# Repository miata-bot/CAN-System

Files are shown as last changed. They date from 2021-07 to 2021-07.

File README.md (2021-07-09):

# Miata CAN System

## Useful Links

* [Gerber Generation for PCBWay](https://www.pcbway.com/blog/help_center/Generate_Gerber_file_from_Kicad.html)
* [Position Generation for PCBWay](https://www.pcbway.com/blog/help_center/Generate_Position_File_in_Kicad.html)

## Underglow Controller

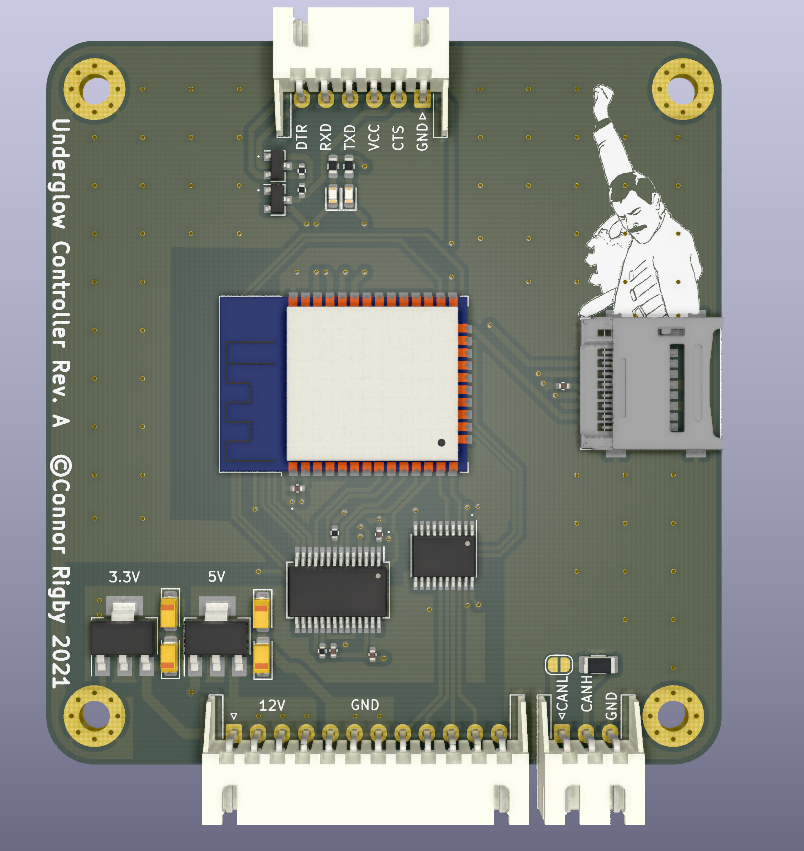
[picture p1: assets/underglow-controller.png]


## Headlight Controller

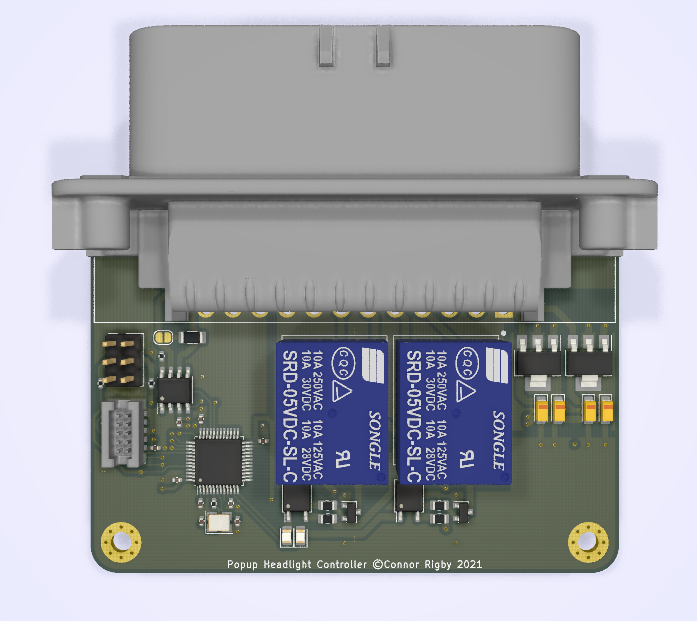
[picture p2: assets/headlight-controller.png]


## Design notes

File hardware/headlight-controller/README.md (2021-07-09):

# LED Controller Hardware design



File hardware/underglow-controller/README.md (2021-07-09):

# LED Controller Hardware design



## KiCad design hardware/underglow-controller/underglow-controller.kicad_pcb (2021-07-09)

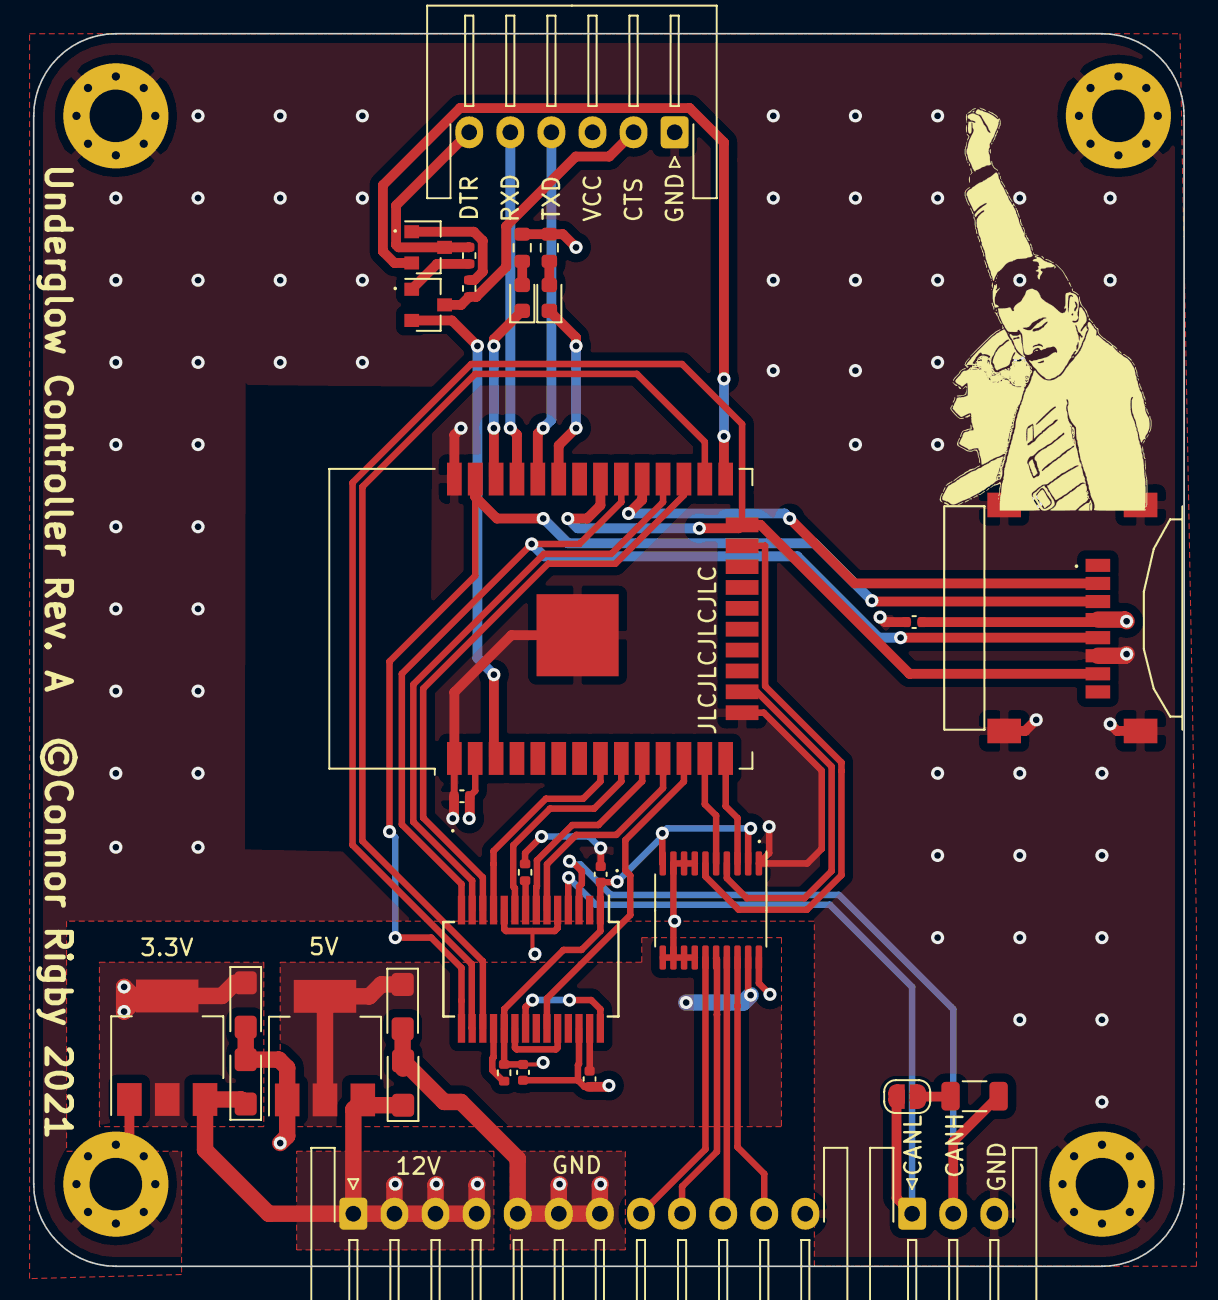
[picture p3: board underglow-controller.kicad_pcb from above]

Board: 4 copper layers, 70.0 x 75.0 mm, 34 parts (0 on the bottom side), 43 nets.

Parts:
C1, C2, C3, C4: 10u; CP_EIA-3216-18_Kemet-A
C5, C6, C7, C8, C9: 100n; C_0402_1005Metric
D1, D2: LED_Small; LED_0603_1608Metric
H1, H2, H3, H4: MountingHole_Pad; MountingHole_3.2mm_M3_Pad_Via
J1: Micro_SD_Card; MOLEX_47219-2001
J2: FTDI; JST_XH_S6B-XH-A-1_1x06_P2.50mm_Horizontal
J3: LEDS; JST_XH_S12B-XH-A-1_1x12_P2.50mm_Horizontal
J4: CAN; JST_XH_S3B-XH-A-1_1x03_P2.50mm_Horizontal
JP1: Jumper_NO_Small; SolderJumper-2_P1.3mm_Open_RoundedPad1.0x1.5mm
Q1, Q2: SS8050; SOT-23
R1, R2, R5, R6: 10k; R_0402_1005Metric
R3, R4: R_Small; R_0603_1608Metric
R7: 120; R_1206_3216Metric
U1: AMS1117-3.3; SOT-223-3_TabPin2
U2: TXS0108EPW; TSSOP-20_4.4x6.5mm_P0.65mm
U3: AMS1117-5.0; SOT-223-3_TabPin2
U4: ESP32-WROOM-32D; ESP32-WROOM-32
U5: MCP25625-x-SS; SSOP-28_5.3x10.2mm_P0.65mm

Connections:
+3V3: C2.1, C5.2, C6.2, C7.2, C8.2, J1.4, R3.1, R4.1, R5.2, U1.2, U2.2, U2.10, U4.2, U5.1, U5.19
+5V: C4.1, C9.2, U2.19, U3.2, U5.27
+12V: C1.1, C3.1, J3.1, J3.2, J3.3, J3.4, U1.3, U3.3
/CANH: J4.1, JP1.1, U5.4
/CANL: J4.2, R7.2, U5.3
/CAN_INT: U4.28, U5.13
/CAN_RX0_BF: U4.27, U5.12
/CAN_RX1_BF: U4.8, U5.11
/CAN_TX0_RTS: U4.12, U5.23
/CAN_TX1_RTS: U4.11, U5.6
/CAN_TX2_RTS: U4.10, U5.7
/FTDI_CTS: J2.2, Q1.3, R2.2
/FTDI_DTR: J2.6, Q2.3, R1.2
/FTDI_RX: J2.5, U4.35
/FTDI_TX: J2.4, U4.34
/GPIO0: Q2.2, U4.25
/LED0: U2.4, U4.16
/LED0_OUT: J3.10, U2.17
/LED1: U2.3, U4.14
/LED1_OUT: J3.11, U2.18
/LED2: U2.5, U4.13
/LED2_OUT: J3.9, U2.16
/LED3: U2.6, U4.23
/LED3_OUT: J3.8, U2.15
/RESET: Q1.2, U4.3
/SD_CLK: J1.5, U4.30, U5.14
/SD_CMD: J1.3, U4.37, U5.15
/SD_D0: J1.7, U4.24, U4.31, U5.16
/SD_D3: J1.2, U4.29
/SPI_CS: U4.26, U5.17
/STATUS0: D1.1, U4.33
/STATUS1: D2.1, U4.36
/XTAL_OUT: U4.9, U5.9
GND: C1.2, C2.2, C3.2, C4.2, C5.1, C6.1, C7.1, C8.1, C9.1, H1.1, H2.1, H3.1, H4.1, J1.6, J1.G1, J1.G2, J1.G3, J1.G4, J2.1, J3.5, J3.6, J3.7, J3.12, J4.3, R6.2, U1.1, U2.1, U2.7, U2.8, U2.9, U2.11, U2.12, U2.13, U2.14, U2.20, U3.1, U4.1, U4.15, U4.38, U4.39, U5.5, U5.10, U5.26
unnamed: D1.2, R3.2
unnamed: D2.2, R4.2
unnamed: JP1.2, R7.1
unnamed: Q1.1, R1.1
unnamed: Q2.1, R2.1
unnamed: R5.1, U5.18
unnamed: R6.1, U5.8
unnamed: U5.20, U5.24
unnamed: U5.21, U5.28

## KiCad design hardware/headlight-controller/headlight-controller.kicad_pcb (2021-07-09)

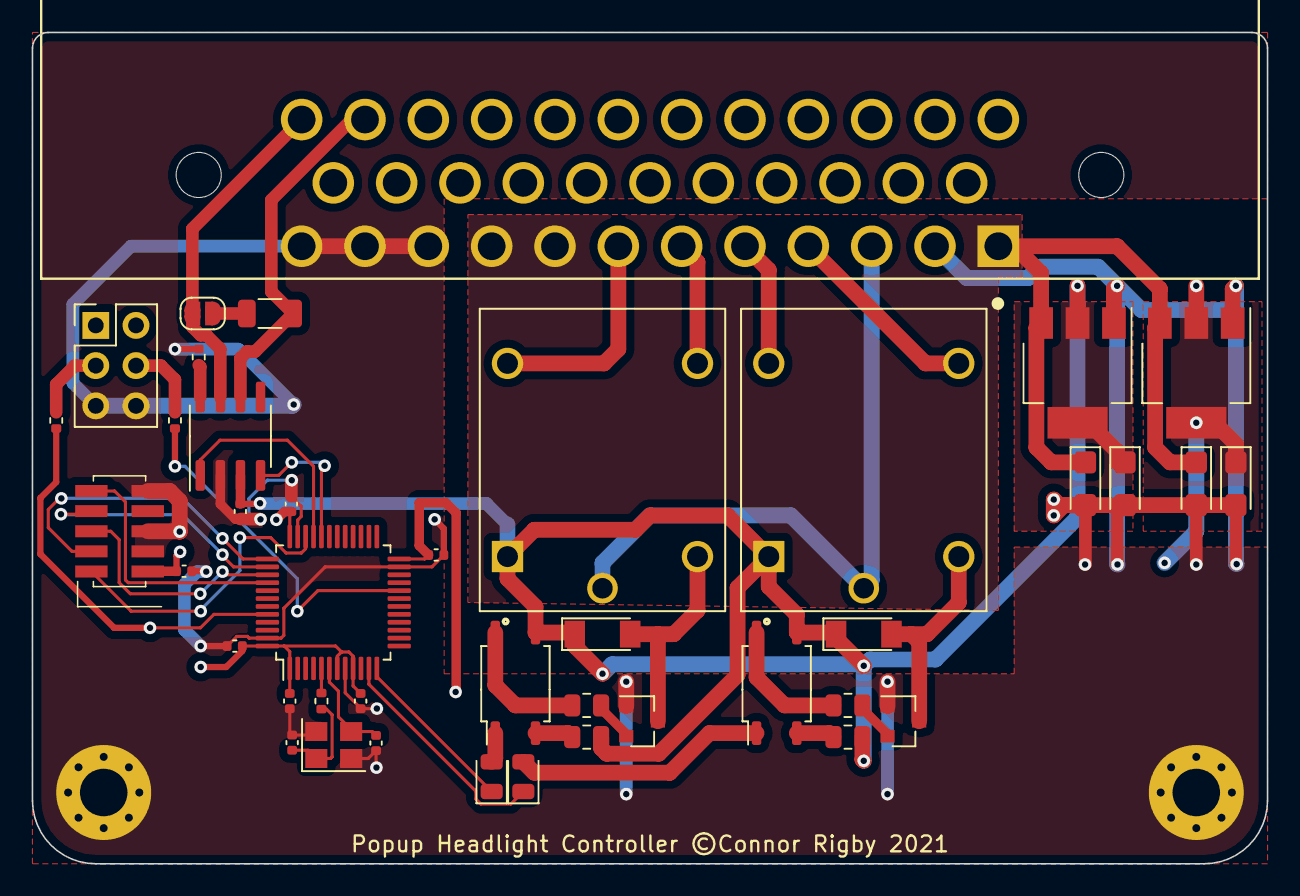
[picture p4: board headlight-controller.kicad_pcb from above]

Board: 2 copper layers, 78.0 x 52.5 mm, 43 parts (0 on the bottom side), 39 nets.

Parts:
C1, C2, C3, C7: 10u; CP_EIA-3216-18_Kemet-A
C4, C6: 12p; C_0402_1005Metric
C5, C8, C9, C10, C11, C12, C13: 100n; C_0402_1005Metric
D1, D2: RED; LED_0805_2012Metric
D3, D4: ZMM5V6; D_MiniMELF
H1, H2: MountingHole_Pad; MountingHole_3mm_Pad_Via
J1: Conn_ARM_JTAG_SWD_10; 20021221-00010C4LF
J2: 776180-1; TE_776180-1
J3: BOOT; PinHeader_2x03_P2.54mm_Vertical
JP1: Jumper_NO_Small; SolderJumper-2_P1.3mm_Open_RoundedPad1.0x1.5mm
K1, K2: SRD-05VDC-SL-C; RELAY_SRD-05VDC-SL-C
Q1, Q2: S8050; SOT-23
R1, R2: 1k; R_0805_2012Metric
R3, R4: 510; R_0805_2012Metric
R5: 120; R_1206_3216Metric
R6, R8: 100K; R_0402_1005Metric
R7: 1M; R_0402_1005Metric
R9: 4.7k; R_0402_1005Metric
U1: AMS1117-3.3; SOT-223-3_TabPin2
U2: AMS1117-5.0; SOT-223-3_TabPin2
U3: STM32F103C8Tx; LQFP-48_7x7mm_P0.5mm
U4: MCP2551-I-SN; SOIC-8_3.9x4.9mm_P1.27mm
U5, U6: EL357N(B)(TA)-G; SOP-4_4.1x4.4mm_P2.54mm
Y1: Crystal_GND24_Small; Crystal_SMD_3225-4Pin_3.2x2.5mm

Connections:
+3V3: C2.1, C5.1, C8.1, C9.1, C10.1, C11.1, C12.1, J1.1, J3.1, J3.2, U1.2, U3.1, U3.7, U3.9, U3.24, U3.36, U3.48
+5V: C7.1, C13.1, D3.1, D4.1, K1.A1, K2.A1, R1.2, R2.2, U2.2, U4.3, U5.3, U6.3
+12V: C1.1, C3.1, J2.1, J2.8, J2.9, U1.3, U2.3
/BOOT0: R6.2, U3.44
/BOOT1: R8.1, U3.20
/CANH: J2.35, JP1.1, U4.7
/CANL: J2.34, R5.1, U4.6
/CAN_RX: U3.32, U4.4
/CAN_TX: U3.33, U4.1
/HL1_DN: J2.7, K1.NC
/HL1_IN: D1.1, U3.12
/HL1_UP: J2.6, K1.NO
/HL2_DN: J2.5, K2.NC
/HL2_IN: D2.1, U3.11
/HL2_UP: J2.4, K2.NO
/HL_COM: J2.3, K1.COM, K2.COM
/HSE_IN: R7.1, U3.5
/HSE_OUT: C6.1, U3.6, Y1.3
/JNTRST: J1.10, U3.40
/SWDCLK: J1.4, U3.37
/SWDIO: J1.2, U3.34
/SWO: J1.6, U3.39
/TDI: J1.8, U3.38
GND: C1.2, C2.2, C3.2, C4.2, C5.2, C6.2, C7.2, C8.2, C9.2, C10.2, C11.2, C12.2, C13.2, H1.1, H2.1, J1.3, J1.5, J1.9, J2.2, J2.10, J2.11, J2.12, J3.5, J3.6, Q1.1, Q2.1, R9.1, U1.1, U2.1, U3.8, U3.23, U3.35, U3.47, U4.2, Y1.2, Y1.4
unnamed: C4.1, R7.2, Y1.1
unnamed: D1.2, U5.1
unnamed: D2.2, U6.1
unnamed: D3.2, K1.A2, Q1.3
unnamed: D4.2, K2.A2, Q2.3
unnamed: J3.3, R6.1
unnamed: J3.4, R8.2
unnamed: JP1.2, R5.2
unnamed: Q1.2, R3.1
unnamed: Q2.2, R4.1
unnamed: R1.1, U5.2
unnamed: R2.1, U6.2
unnamed: R3.2, U5.4
unnamed: R4.2, U6.4
unnamed: R9.2, U4.8

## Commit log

2021-07-07 Progress on routing
    [miata-underglow.kicad_pcb, miata-underglow.sch]
2021-07-08 More routing progress
    [miata-underglow.kicad_pcb, miata-underglow.sch]
2021-07-08 p much complete i think
    [miata-underglow.kicad_pcb]
2021-07-08 Hardware Rev A
    [miata-underglow-B_Cu.gbl, miata-underglow-B_Mask.gbs, miata-underglow-B_Paste.gbp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]
2021-07-08 Add Second controller for Headlights
    [miata-headlight-controller.kicad_pcb, miata-headlight-controller.sch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]
2021-07-09 Restructure project
    [headlight-controller.kicad_pcb, headlight-controller.sch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]
2022-03-17 Add new underglow controller
    [OSD335x.kicad_sch, canlink.kicad_pcb, canlink.kicad_sch]

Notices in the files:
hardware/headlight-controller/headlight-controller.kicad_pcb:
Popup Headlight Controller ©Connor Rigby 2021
